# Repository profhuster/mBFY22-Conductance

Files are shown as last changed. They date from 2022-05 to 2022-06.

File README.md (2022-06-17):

# Conductivity *versus* Temperature using CircuitPython on a Microcontroller
# Introduction

The ESP32-S2 is an amazing little microcontoller. It has built in WiFi 
a true DAC (Digital to Analog Converter), multiple ADC's (Analog to
Digital Converters), and DIO (Digital In Out) pins.
The DAC is relatively rare in microcontollers but it
enables some unique experiments. In this project you will use the DAC to
control the voltage to a device, and two of the ADC's 
to measure the resistance (inverse of the conductance) of a device. 
The microcontroller will measure both the current through and voltage
across the device as the voltage across it changes and fit the result to
a line to get the resistance. I also have a list in an appendix of other 
applications of this project.

To make the project more interesting you will also wire a Type K
thermocouple to a microcontroller breakout board using a digital
protocol. A type K thermocouples can read from -200 °C to 1350 °C. You can
use the thermocouple to measure the temperature coefficient of the resistance and
other experiments.

# Guide to Project Files
- [Main Guide to Project](https://github.com/profhuster/mBFY22-Conductance/blob/19ab132cf7104593252cab7fcc826aaca93124e6/Conductivity-CircuitPython_22d.pdf) You should download 
this document and keep it open as you work.
- [Setting Up CircuitPython](https://github.com/profhuster/mBFY22-Conductance/blob/bd73491f5e60a5675a0e9d870f6eabee54c16e31/Setting_Up_CircuitPython_22a.pdf) This is the guide to installing 
CircuitPython on a Microcontroller. You need to do this before working on the project.

[Back to mBFY22 page](https://github.com/profhuster/mBFY22)

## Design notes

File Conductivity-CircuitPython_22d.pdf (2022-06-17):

Project Guide | Conductivity using CircuitPython Microcontollers | June 2022

INTRODUCTION
The ESP32-S2 microcontoller has a true DAC (Digital to Analog Converter.) This feature is relatively rare in microcontollers but it enables some unique experiments. In this project you will use the DAC to control the voltage to a device, and two of the ADC's (Analog to Digital Converters) to measure the resistance (inverse of the conductance) of a device.
The microcontroller will measure both the current through and voltage across the device as the voltage across it changes and fit the result to a line to get the resistance. I also have a list in an appendix of other applications of this project.
To make the project more interesting you will also wire a Type K thermocouple to a microcontroller breakout board using a digital protocol. A type K thermocouples can read from -200 °C to 1350 °C. You can use them to measure the temperature coefficient of the resistance and the transition temperature of high Tc superconductors. I set up a GitHub repository with all of the documents and code for this project at
https://github.com/profhuster/mBFY22-Conductance.

BILL OF MATERIALS
Items needed with approximate cost.
- Case, 3D printed – $2 of PLA filament.
- Half breadboard – $5.
- Lolin S2Mini microcontroller board – $5.
∘ Option: TinyS2 – ESP32-S2 Development Board from AdaFruit – $19.
∘ Adafruit ESP32-S2 Feather – $18.
- Thermocouple breakout board, MAX31855 – $15.
- Type K thermocouple – $10.
- Miscellaneous electronic supplies:
∘ 100 Ω resistor.
∘ Sample resistor <= 100 Ω.
∘ Hook up wire, 22AWG Solid Core.
- Total: $56

Tools, Equipment, and Software:
- Computer.
∘ Need to install Thonny editor/IDE. ∘ Optional: jupyter notebook.
- USB C cable.
- Soldering iron.
- Wire strippers.
- Optional:
∘ Wire cutter.
∘ Needle-nosed pliers.
Conductivity-CircuitPython_22d.odt | — 1 of 16 — | 2022-06-15, 20:26

Project Guide | Conductivity using CircuitPython Microcontollers | June 2022

GETTING STARTED
Follow the steps in the Setting Up CircuitPython to load CircuitPython onto the Lolin S2Mini microcontroller.The Lolin S2Mini.

HARDWARE
The pin assignments for the S2Mini are in Figure 1. To use on a
breadboard, I only use the outside pins. Almost any pin can be

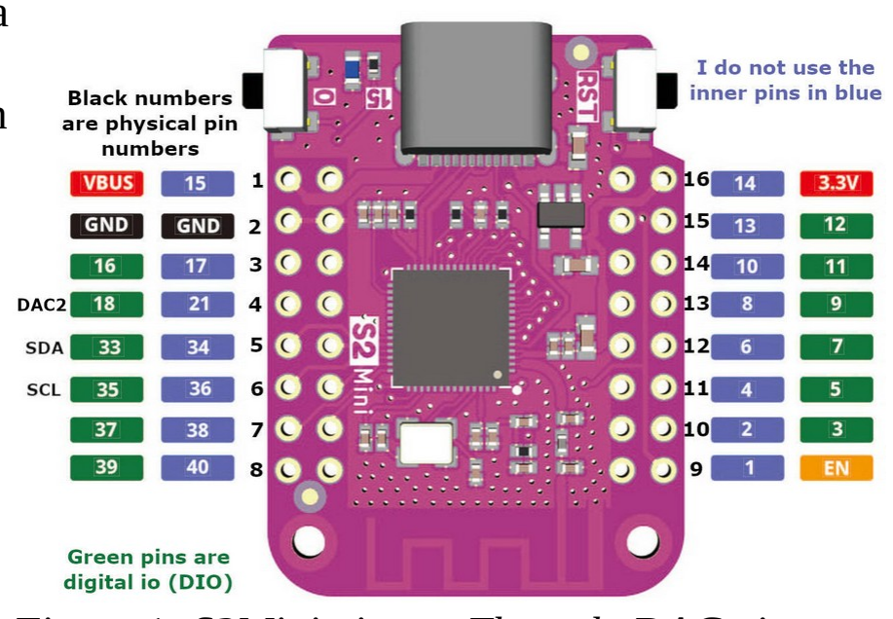
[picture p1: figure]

used for digital in/out and ADC, but only pins 18 (and 17 which is not wired up) have a DAC which can be used to output a voltage. The DAC has 8-bits of resolution (0 – 0xff.) Circuit-Python maps the DAC resolution to 16-bits (0 – 0xffff) so setting pin 18 from 0 to the max should gives= an output voltage of 0 to 3.3 V. In the first project you will test this out.

DAC Complication
The DAC’s on the ESP32S2 have internal pull-up resistors, so to get a decent output voltage range you need to supply a pulldown resistor. Figure 2 shows the output voltage versus DAC setting for different pulldown resistors. To get a good range on the DAC, we need to have 1 kΩ or less connected to the DAC

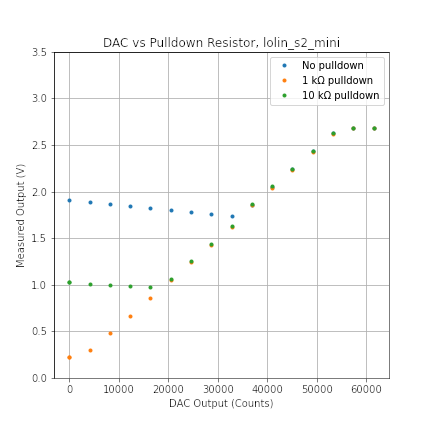
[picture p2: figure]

pin. Later when we design a circuit to measure conductance, we need to make sure it has an equivalent resistance of 1 kΩ or less.

Conductivity-CircuitPython_22d.odt | — 2 of 16 — | 2022-06-15, 20:26

Figure 1: S2Mini pinout. The only DAC pins are 17 on the inside row and 18. Not all pins have ADC’s. We will use pins 9, 11, and 12.

Figure 2: DAC output on pin 18 with different pulldown resistors.

Project Guide | Conductivity using CircuitPython Microcontollers | June 2022

PROJECT 1 – TAKE DAC VOLTAGE VERSUS DAC COUNTS DATA
See Figure 3 for a picture of the circuit.
- Plug the S2Mini into a breadboard.
- Wire GND to the blue “–“ power rail.
- Wire pin 16 to row 12 after the S2Mini.
- Wire pin 18 to the same row.
- Wire a 100 Ω resistor from the same row and to the ground rail. Note: the figure shows a 1 kΩ instead of 100 Ω. The Code
First you need to load the libraries we will be using to the S2Mini. From the zip file, locate the folder lib. Drag it to the CIRCUITPY disk. If it prompts you that the folder there exists, answer Replace, or copy anyway.
In your code the libraries (sometimes called modules) are im-

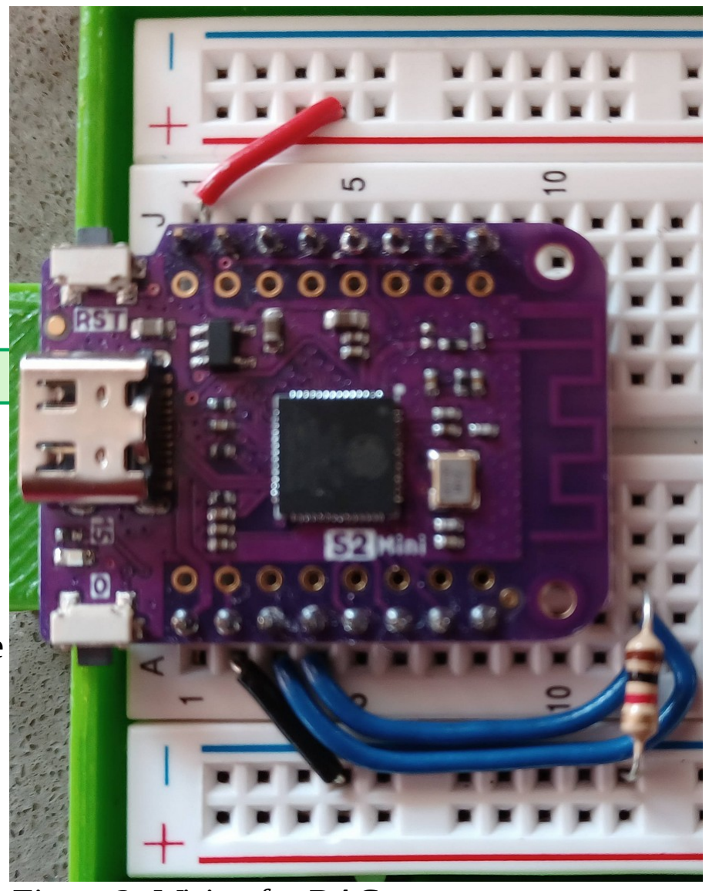
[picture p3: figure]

ported first. The library board imports the pins available for the specific board and a few other items. I encourage that you explore these libraries. You can do that at the python prompt by typing, for example,
>>> import board
>>> help(board)
>>> dir(board)
I do this a lot with libraries and objects so I can learn what can be done with CPy. The other source of information is searching the CircuitPython web site. (https://docs.circuitpython.org/en/latest/) The library analogio handles DAC and ADC functions for microcontrollers. I also import sleep and sqrt from standard python libraries.
This file for this code is testDAC.py. Note: The code on GitHub is slightly different. Please us the GitHub code. import board
import analogio
from time import sleep
from math import sqrt
Next I create variables that parameterize the program behavior. I strongly advocate the programming proverb Never bury a constant in your code; assign it to a variable or constant at the top of your code. Here I had to look up which pins are DAC compatible (pins 17 & 18) and which are ADC compatible (many pins.)
For each data point I I sleep for tADC seconds to give time for the DAC to settle then average over nAvg points. The variable counts sets the DAC voltage, the variables countsMax and countsInc set the loop for stepping the DAC. The CircuitPython library maps all DAC’s to 16 bits, so I use hex to code the maximum value as 0xffff. Setting an increment of 0x0400 gives 64 data point in the scan. I find hex easier than remembering 65535 and 1024.
dacPin = board.IO18
adcPin = board.IO16
nAvg = 10
tADC = 0.01
countsMax = 0xffff
countsInc = 0x0400
Conductivity-CircuitPython_22d.odt | — 3 of 16 — | 2022-06-15, 20:26

Figure 3: Wiring for DAC test.

Project Guide | Conductivity using CircuitPython Microcontollers | June 2022

To grab a pin for analog use, the analogio library does a lot of work for you. I set up the variable dToV to convert counts to voltage for ADC readings.
dac = analogio.AnalogOut(dacPin)
adc = analogio.AnalogIn(adcPin)
dToV = adc.reference_voltage / 0xffff
In this section you can input a comment that will get stored in the data file. I used this to describe the pull down resistors. I also print important information about the microcontoller and the code. The board_id variable describes the microcontoller, in this case the string is lolin_s2_mini. Note I print out the parameters for the run. Starting these lines with # makes it easier to import the data into an analysis program.
comment = input("Enter comment: ")

print(f"# board_id = {board.board_id}")
print(f"# dacPin: {dacPin}, adcPin: {adcPin}, dToV: {dToV}")
print(f"# nAvg: {nAvg}, tADC: {tADC}")
print(f"# {comment}")
Next I define a function that returns an ADC reading and its standard deviation. This is where the parameters nAvg and tADC are used. I strongly encourage my students to always be thinking about uncertainties in measurement. In this case the standard deviation tell you how spread out the measurements are.
def readADC():
sum = 0.0
sumSq = 0.0
for i in range(nAvg):
reading = adc.value * dToV sum += reading
sumSq += reading * reading sleep(tADC)

avg = sum / nAvg
std = sumSq / nAvg - avg * avg if std <= 0.0:
std = 0
else:
std = sqrt(sumSq / nAvg - avg * avg) return (avg, std)
Below is the main loop. It set the DAC value, sleeps, then reads the ADC and prints the result. I always use a # in the first line of comments, and make the data in comma separated columns, the CSV format. This makes reading and analyzing the data easy. Also note I manually add the last point otherwise I wouldn’t get a data point for the maximum value of the DAC.
for out in range(0, countsMax, countsInc):
print(f"{out}, ", end="")
dac.value = out
sleep(0.1)
(V, dV) = readADC()
print(f"{V}, {dV}")

out = 0xffff
print(f"{out}, ", end="")
dac.value = out
sleep(0.1)
(V, dV) = readADC()
print(f"{V}, {dV}")
Conductivity-CircuitPython_22d.odt | — 4 of 16 — | 2022-06-15, 20:26

Project Guide | Conductivity using CircuitPython Microcontollers | June 2022

These last two lines release the pins. If these lines are not included, when you rerun the code it can’t grab the pins.
dac.deinit()
adc.deinit()
Analyzing the DAC Data
The output is written in the Shell window at the bottom of Thonny. Below is an example run of the output: # board_id = lolin_s2_mini
# dacPin: board.IO18, adcPin: board.IO16, dToV: 5.03547e-05

# nAvg: 10, tADC: 0.01

# 1 k pulldown

0, 0.241481, 0.00211784
4096, 0.297284, 0.00316913 8192, 0.487575, 0.00245358 12288, 0.672477, 0.00304931 16384, 0.869571, 0.00223759 20480, 1.06437, 0.00316442 24576, 1.26018, 0.00292969 28672, 1.45058, 0.00276214 32768, 1.64508, 0.00169146 36864, 1.85078, 0.000976563 40960, 2.04587, 0.00195313 45056, 2.23348, 0.00195313 49152, 2.43148, 0.00239208 53248, 2.63266, 0.00338291 57344, 2.68199, 0.00276214
61440, 2.68199, 0.00276214
65535, 2.68199, 0.00276214
I cut and paste this into an editor, edit to delete any extra lines and save it with a file name that encodes the date and time the data was taken, 2022-04-28-1546.csv, for example.
I use jupyter notebooks running python to analyze the data. They are in the jupyter folder on GitHub. One nice thing about the CSV data format is that is can be read by many programs including spreadsheets like Microsoft Excel. Figure 4 is a plot from my jupyter notebook plotDAC.ipynb.
The curve looks linear between 5000 and
45000 counts and it does not go down to
zero volts nor up to 3.3 V. These are limitations we will have to work with when we make a conductivity measurement.
I took the data in Figure 2 using this program and different pull down resistors.

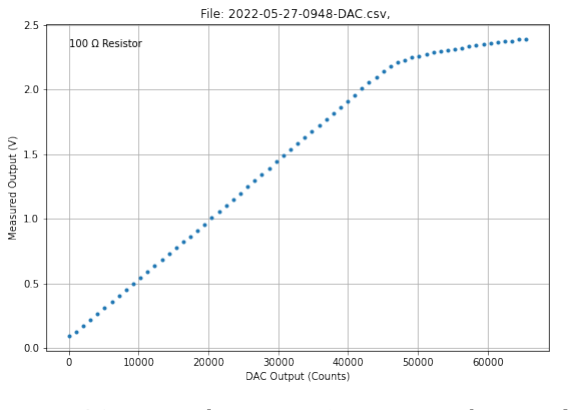
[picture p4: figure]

Conductivity-CircuitPython_22d.odt | — 5 of 16 — | 2022-06-15, 20:26

Figure 4: DAC output voltage versus input counts. The curve depends on the value of the pulldown resistor.

Project Guide | Conductivity using CircuitPython Microcontollers | June 2022

PROJECT 2: TWO-WIRE CONDUCTIVITY MEASUREMENT The next project will use the microcontoller to measure the resistance (inverse of the conductivity) of a device.
The basic idea, Figure 5, is that the voltage drop across the sensing resistance is the current through the sample. So

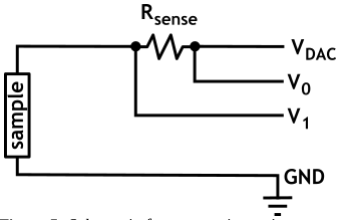
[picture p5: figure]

I sample=

V 0−V 1

Rsense
and

Vsample=V1
So

Rsample=

V sample

I sample

We will step VDAC from 0 to 3.3V, so a graph of Vsample versus Isample should be a straight line with a slope of Rsample. For each DAC setting, we will read V0 and V1 multiple times and get an uncertainty for each. We will carry the uncertainty through the linear fit to calculate an uncertainty for the resistance.
I wired this circuit up with a 100 Ω sense resistor and 69 Ω resistor for the sample.
Figure 6 shows a graph of V0 and V1 versus DAC setting. You can see at counts less than about 4000 the curves flattens out or

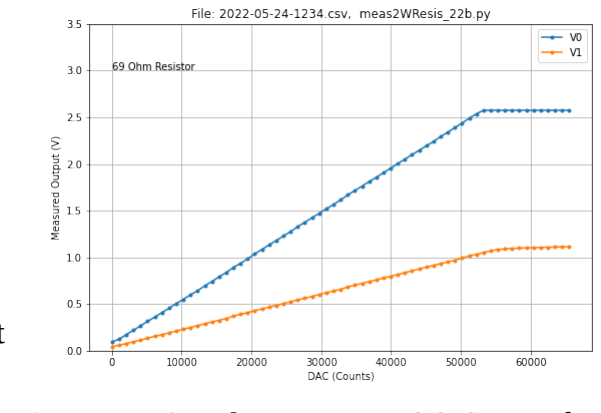
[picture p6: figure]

slightly rises. I believe this is an effect of the pull up resistor. At the higher end, the voltage does not go above 2.58 V. I believe this is a limit of the ADC. In between the two graphs look linear. In the software I will limit the data to DAC counts to
greater than 4000 and voltages less than 2.50.
In the software I actually average some number of ADC readings together at each DAC step. This gives more accuracy to each data point and I calculate the standard deviation for the point, so I also have an uncertainty estimate for each point.
Conductivity-CircuitPython_22d.odt | — 6 of 16 — | 2022-06-15, 20:26

Figure 5: Schematic for a two-wire resistance measurement.

Figure 6: V0 and V1 versus DAC Counts for a 60 Ohm resistor as a sample.

Project Guide | Conductivity using CircuitPython Microcontollers | June 2022

I do a linear fit with uncertainty to the data.
This gives both a measurement of the sample
resistance, but also an uncertainty estimate for
the resistance. Figure 7 is an example of one measurement.
Once the code for making the measurement

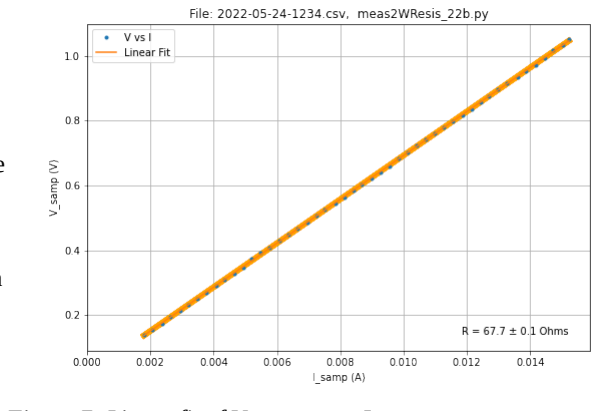
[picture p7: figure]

was checked and debugged, the basic resistance measurement is in a loop that measures the resistance versus time. Figures 8 & 9 show a run where the resistance is repeated. From running the program versus time, the standard deviation of the resistance measurements is about 0.1 Ω.

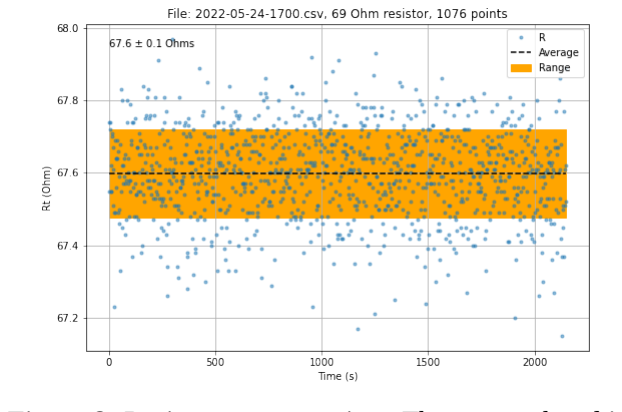
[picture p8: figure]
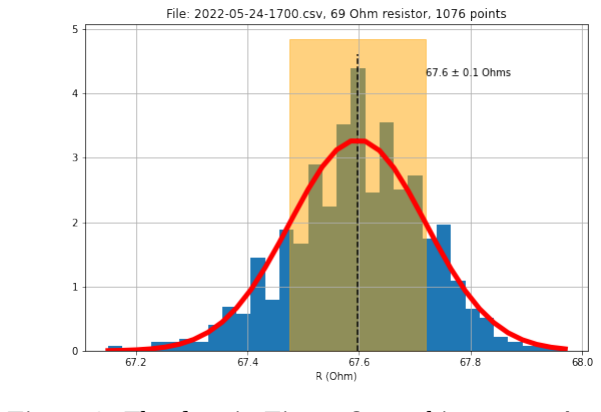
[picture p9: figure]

Conductivity-CircuitPython_22d.odt | — 7 of 16 — | 2022-06-15, 20:26

Figure 7: Linear fit of Vsample versus Isample.

Figure 8: Resistance versus time. The orange band is +/- one standard deviation.

Figure 9: The data in Figure 8 as a histogram. A normal distribution matching the average and standard deviation is shown.

Project Guide | Conductivity using CircuitPython Microcontollers | June 2022

The Hardware
A picture of the circuit is in Figure 10. The sample is a
68 Ω resistor. You can see the wires are tightly twisted and soldered to a two pin connector.
To wire the circuit:
- Wire the 3.3V to the “+” power rail (red.)
- Wire pin GND to the blue “-” ground rail (black.)
- Wire the DAC, pin 18 to the 100 Ω sensing resistor. Also wire that end of the resistor to pin DIO5 which is V0. They are the yellow wires in the figure.
- Finally the last wire of the sample connector is wired to ground, the “-” ground rail (black.)

The Code

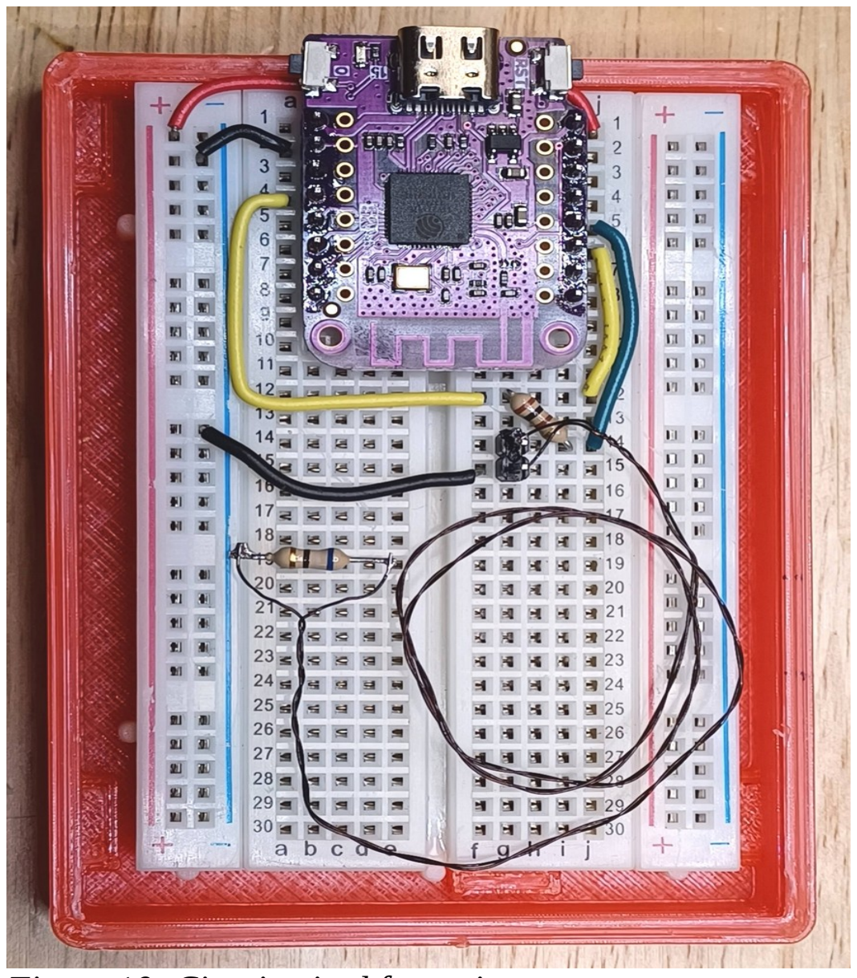
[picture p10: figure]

A lot of the code is the same as the previous project. The file is meas2WResis.py. I will just highlight the new code. The code below does a fit to a straight line and weights the fit by the uncertainty in the y-coordinate. Since I did not use numpy because only a subset of numpy is available as the ulab library. Instead I use the array library so I have to explicitly loop over the data. The function returns the best fit values for the intercept and slope and the covariance matrix.
# Do linear fit

def linReg(n, x, y, sigY):
"""linReg - linear fit with returned uncertainties.""" invSigY2 = 0
S = 0.0
Sx = 0.0
Sy = 0.0
Sxx = 0.0
Sxy = 0.0
for i in range(n):
invSigY2 = 1.0 / (sigY[i] * sigY[i]) S += invSigY2
Sx += x[i] * invSigY2
Sy += y[i] * invSigY2
Sxx += x[i] * x[i] * invSigY2
Conductivity-CircuitPython_22d.odt | — 8 of 16 — | 2022-06-15, 20:26

Figure 10: Circuit wired for resistance measurement. The sample is attached by a pair of twisted wires to the circuit.

Project Guide | Conductivity using CircuitPython Microcontollers | June 2022

Sxy += x[i] * y[i] * invSigY2

Delta = S * Sxx - Sx * Sx
a = (Sxx * Sy - Sx * Sxy) / Delta b = (S * Sxy - Sx * Sy) / Delta varA = Sxx / Delta
varB = S / Delta
covAB = -Sx / Delta
return (a, b, varA, varB, covAB) Next is the function that returns the resistance. First I create arrays for intermediate data and define first. # Make arrays for data
ISamp = array('f', nCounts * [0.0])
VSamp = array('f', nCounts * [0.0])
sigV = array('f', nCounts * [0.0])
first = True # Boolean to print nGood only once
The next part of the code loops over the DAC values. If you are not familiar with enumerate(), it is an iterator over an array, but it returns two values: a counting index, here the variable i, and the next array value, out. Next, the first time it is called, it prints the number of data points used in the linear fit. Finally it calculates the uncertainty in the resistance as the square root of the variance and returns both the fit value and its uncertainty.
def measureR():
global first, ISamp, VSamp, sigV

# Collect the data into arrays

nGood = 0
for (i, out) in enumerate(range(0, countsMax, countsInc)): dac.value = out
sleep(tADC)
(V0, dV0) = readADC(v0)
if out > 4000 and V0 < 2.65:
| (V1, dV1) = readADC(v1) ISamp[nGood] = (V0 - V1) / rSens VSamp[nGood] = V1 sigV[nGood] = sqrt(dV0 * dV0 + dV1 * dV1) if debug:

print(f"{out}, {ISamp[nGood]}, {VSamp[nGood]}, {sigV[nGood]}")
| nGood += 1

# On first call print the number of data points if first:

first = False
print(f"# {nGood} good points")

# Fit data to a line

(a, resis, varA, varB, covAB) = linReg(nGood, ISamp, VSamp, sigV) uncResis = sqrt(varB)
if debug:
print(f"# Resistance = {resis:.2f}, {uncResis:.2f}")

# Return resistance and uncertainty

return (resis, uncResis)
Conductivity-CircuitPython_22d.odt | — 9 of 16 — | 2022-06-15, 20:26

Project Guide | Conductivity using CircuitPython Microcontollers | June 2022

Finally the code below is the main loop that takes data. The function monotonic() returns the number of seconds since the microcontoller booted. The entire loop is in a try – finally structure. The reason for this is to release the pins when the program is stopped with a <Ctrl>C keystroke.
# Loop forever taking data

# Stop with ^C

t0 = monotonic()
try:
while True:
while monotonic() < t0 + loopTime: sleep(0.01)
t0 += loopTime
(R, sigR) = measureR()
print(f"{monotonic():.1f}, {R:.2f}, {sigR:.2f}") finally:
# Clean up

print("# Cleaning up")
dac.deinit()
v0.deinit()
v1.deinit()
Conductivity-CircuitPython_22d.odt | — 10 of 16 — | 2022-06-15, 20:26

Project Guide | Conductivity using CircuitPython Microcontollers | June 2022

PROJECT 3 – RESISTANCE VERSUS TEMPERATURE
The final step is to use a breakout board to measure the sample temperature with a thermocouple. A Type K thermocouple has a useful range of -200 oC (73 K) to 1350 oC. They are nice because they can be used for liquid nitrogen experiments. Thermocouples are hard to use without specialized circuits, but don’t fear! They are nicely handled with a $16 breakout board like this one. (https://www.adafruit.com/product/4101) We are going to add this to the previous project.
Hardware

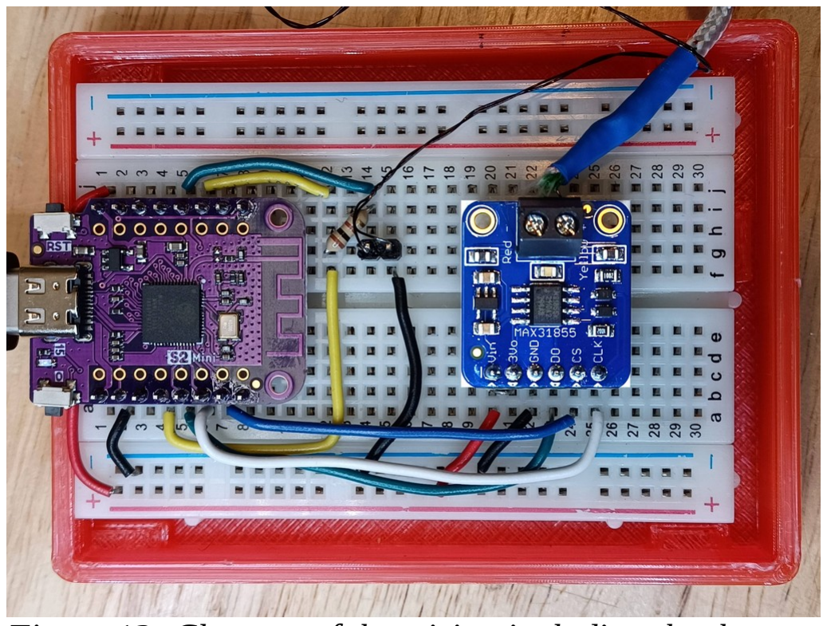
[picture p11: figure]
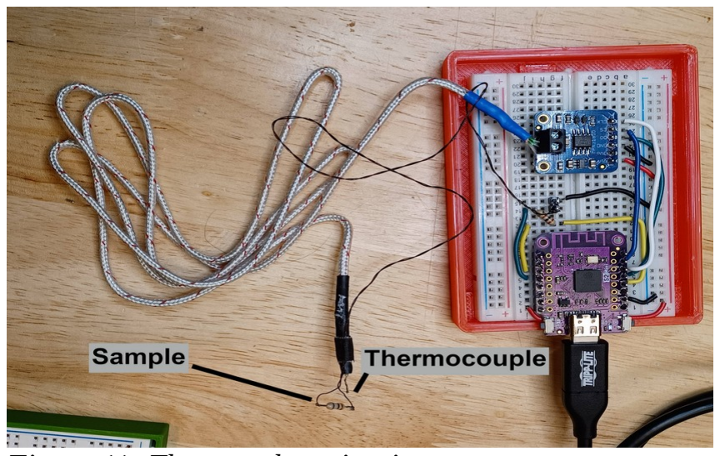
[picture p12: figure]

The overall device is shown in Figure 11, a close up of the wiring is in Figure 12.
The wiring is the same as the previous plus:
- Plug the breakout board into the breadboard.
- Wire S2Mini pin DIO33 to the DO (Data Out) pin on the breakout board (green wire.)
- Wire S2Mini pin DIO35 to the SCL pin on the breakout board (white.)
- Wire S2Mini pin DIO37 to the CS pin on the breakout board (blue.)
- Wire the 3.3V pin of the S2Mini across to the red “+” power rail on the breadboard (red.)
- Wire the breakout board VIN to the “+” power rail (red.)
- Put a bare wire between the VIN and 3V3 pins on the breakout board. (This can’t be seen in the figure because it is underneath the breakout board.
- Wire the GND pin on the breakout board to the “-” ground rail on the breadboard (black.)
- Screw the thermocouple into the breakout board. Once it is running, hold the thermocouple. If the temperature goes down, switch the wires.
The Code
The code is in file meas2WRvsT.py. In addition to the code for Project 2 it has the following code:
import digitalio
import busio
import adafruit_max31855
import microcontroller
import watchdog
Conductivity-CircuitPython_22d.odt | — 11 of 16 — | 2022-06-15, 20:26

Figure 11: The complete circuit.

Figure 12: Close up of the wiring including the thermocouple breakout board.

Project Guide | Conductivity using CircuitPython Microcontollers | June 2022

The first three lines import libraries needed for the MAX31855 breakout board. For a description of how this code was developed, see the appendix in the handout 2022-mBFY-Introduction.
spi = busio.SPI(board.IO35, board.IO36, board.IO33)
cs = digitalio.DigitalInOut(board.IO37)
max31855 = adafruit_max31855.MAX31855(spi, cs)
The first line defines the SPI interface using the pins designated. The second line defines the chip select pin. The last line uses the AdaFruit library for this breakout board. I chose this board because it is only for Type K thermocouples. If you have a different type of thermocouple or a platinum resistance thermometer, there are other boards you can use.
The first three lines import libraries needed for the MAX31855 breakout board. For a description of how this code was developed, see the appendix in the handout 2022-mBFY-Introduction. Once the breakout board is ready reading the temperature is as simple as reading the value of max31855.temperature. Easy peasy!
The code allows the user to enter a comment that is stored in the data file, but I didn’t want the code to hang up if the data be taken remotely. The solution is a watchdog timer. You set the watchdog and if it isn’t fed or canceled, it goes off and does some contingent action. Here is the code around getting a comment:
wdt = microcontroller.watchdog
wdt.timeout = 10
wdt.mode = watchdog.WatchDogMode.RAISE
try:
comment = input("Enter comment: ")

except watchdog.WatchDogTimeout as e:
comment = "No comment"
wdt.deinit()
It sets the watchdog with a 10 second timeout. It set the mode of the watchdog to raise an exception. If you don’t set the mode, the microcontoller is completely reset!
Now the line getting a comment is in a try – except structure. If no comment is entered in 10 seconds, it sets the comment to “no comment”.
Finally the watchdog is deinitialized, or turned off.
print(f"{monotonic():.1f}, {R:.2f}, {sigR:.2f}, {max31855.temperature:.2f}")
Finally, getting the temperature is easy. The dynamic variable max31855.temperature retrieves the thermocouple temperature.

AN EXPERIMENT
With the setup as built I measured the resistance versus
temperature. I do not know what type of resistor it is in the device. I taped the sample and thermocouple wires

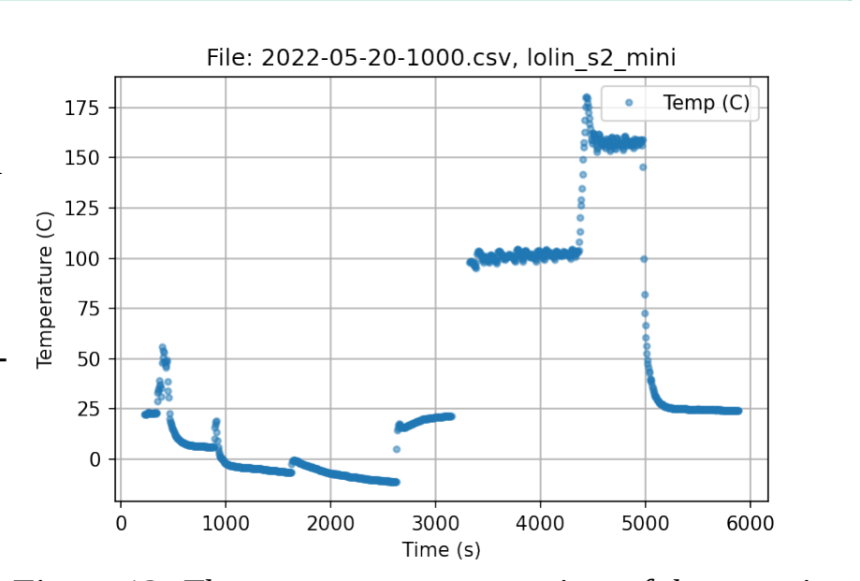
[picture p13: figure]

together to the thermocouple was about 2 mm away from the sample.
Figure 13 shows the temperature versus time as I cooled and heated the sample and thermocouple.
The result is shown in Figure 14. The temperature coefficient of resistance is -168 ppm/°C. (ppm is parts per million.)
Conductivity-CircuitPython_22d.odt | — 12 of 16 — | 2022-06-15, 20:26

Figure 13: The temperature versus time of the experiment.

Project Guide | Conductivity using CircuitPython Microcontollers | June 2022

Finally, Figure 14 shows the resistance is temperature
dependent. The temperature dependence is usually give
as ppm (Parts Per Million) per degree Celsius. The value
of about -200 ppm/°C. I do not know what type of resistor this is, but, for example, carbon film resistors are quoted as having a temperature coefficient of -200

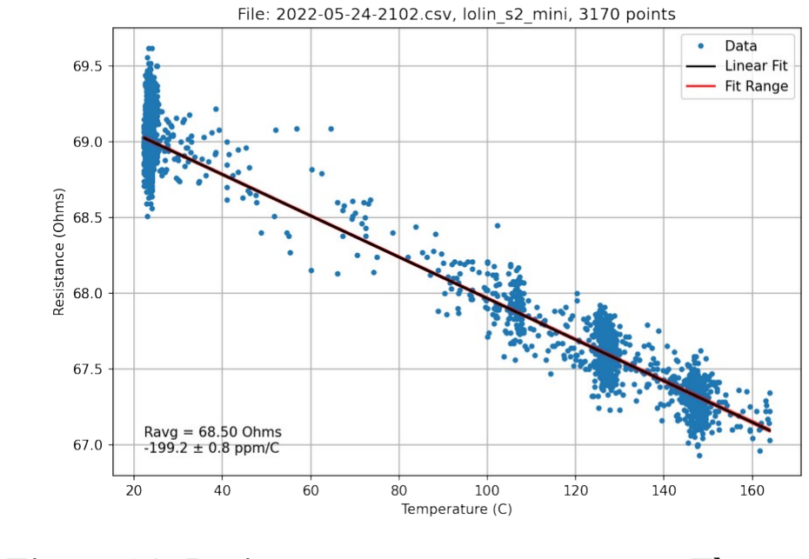
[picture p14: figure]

ppm/°C, so this value is right on that value, probably just a change occurance.

EXTENSION PROJECT: FOUR-WIRE CONDUCTIVITY MEASUREMENT The next project will use the microcontoller to measure the re-

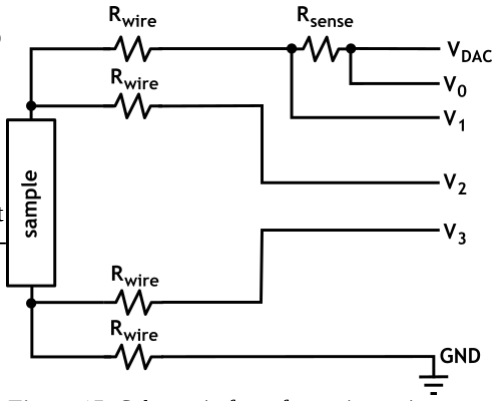
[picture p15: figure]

sistance (inverse of the conductivity) of a device. If you want to
put the device some distance away, like in a cryostat, the resistance of the wires would be added to the resistance of the device. This can be significant for some experiments. A standard, and very clever, method to avoid the added resistance of the wire is to use a four-point measurement technique.
The basic idea, Figure 5, is that you two wires to supply current through the sample, and two different wires to measure the voltage across the sample as close to the sample as possible. Voltage measurements are be made with only tiny amounts of current, so the ohmic loss in the voltage-measuring wires is insignificant. Also since tiny currents flow through the voltage measuring circuit, nearly all of the current measured flowing through the sensing resistor also flows through the sample. So

I sample=

V0−V1

Rsense
and

Vsample=V2−V3

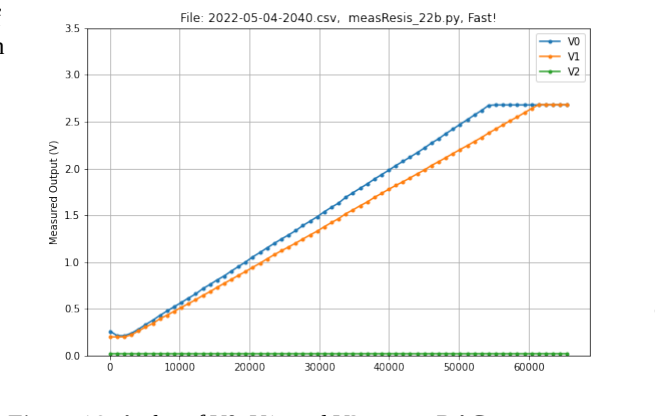
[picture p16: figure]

We will step VDAC from 0 to 3.3V, so a graph of Vsample versus Isample should be a straight line with a slope of Rsample.
I wired this circuit up with a 100 Ω sense resistor and about 69 Ω for the sample.
Figure 6 shows a graph of V0 and V1 versus DAC setting. You can see at counts less than
about 4000 the curves flattens out or slightly
Conductivity-CircuitPython_22d.odt | — 13 of 16 — | 2022-06-15, 20:26

Figure 15: Schematic for a four-wire resistance measurement. The Rwire's represent potentially long wires of unknown resistance.

Figure 16: A plot of V0, V1, and V3 versus DAC counts.

Figure 14: Resistance versus temperature. The temperature coefficient of resistance is about -200 ppm/°C.

Project Guide | Conductivity using CircuitPython Microcontollers | June 2022

rise. I believe this is an effect of the pull up resistor. At the higher end, the voltage does not go above 2.65 V. I believe this is a limit of the ADC. In between the two graphs look linear. In the software I will limit the data to DAC counts greater than 4000 and voltages less than 2.65.
In the software I actually average some number of ADC readings together at each DAC step. This gives more accuracy to each data point and I calculate the standard deviation for the point, so I also have an uncertainty estimate for each point.
I do a linear fit with uncertainty to the data.
This gives both a measurement of the sample
resistance, but also an uncertainty estimate for the resistance. Figure 7 is an example of one measurement.
Once the code for making the measurement

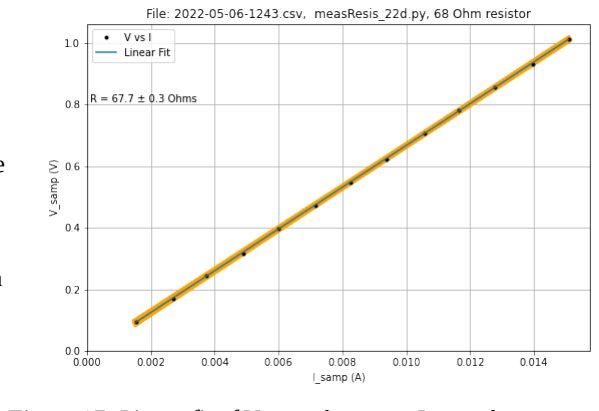
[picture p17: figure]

was checked and debugged, the basic resistance measurement is in a loop that measures the resistance versus time. Figures 8 & 9 show a run where the resistance is repeated. From running the program versus time, the standard deviation of the resistance measurements is about 0.1 Ω.

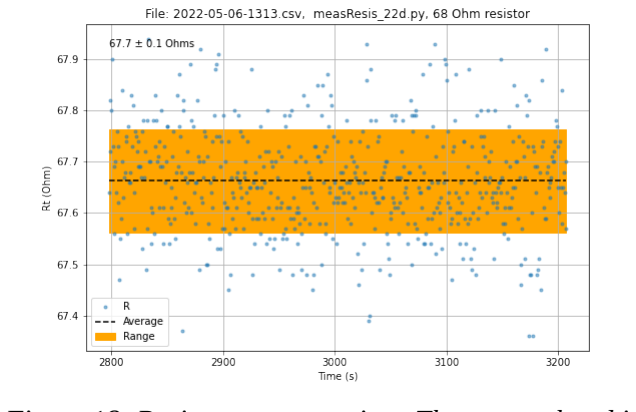
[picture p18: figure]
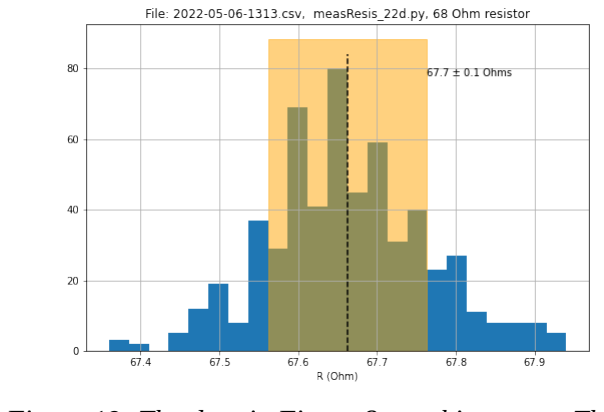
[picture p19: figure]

Conductivity-CircuitPython_22d.odt | — 14 of 16 — | 2022-06-15, 20:26

Figure 17: Linear fit of V_sample versus I_sample.

Figure 18: Resistance versus time. The orange band is +/- one standard deviation.

Figure 19: The data in Figure 8 as a histogram. The data appears to be normally distributed.

Project Guide | Conductivity using CircuitPython Microcontollers | June 2022

The Hardware
A picture of the circuit is in Figure 10. The sample is a
68 Ω resistor. You can see there are two wires soldered to each end of the resistor. The four wired are tightly twisted and soldered to a four pin connector.
To wire the circuit:
- Wire pin GND to the blue “-” ground rail.
- Wire the DAC, pin 18 to the 100 Ω sensing resistor. Also wire that end of the resistor to pin DIO5 which is V0. They are the yellow wires in the figure.
- The other end of the sensing resistor is wired to both the sample connector and pin DIO7, V1 (green.)
- The second wire of the sample connector is wired to pin DIO9, V2 (blue.)

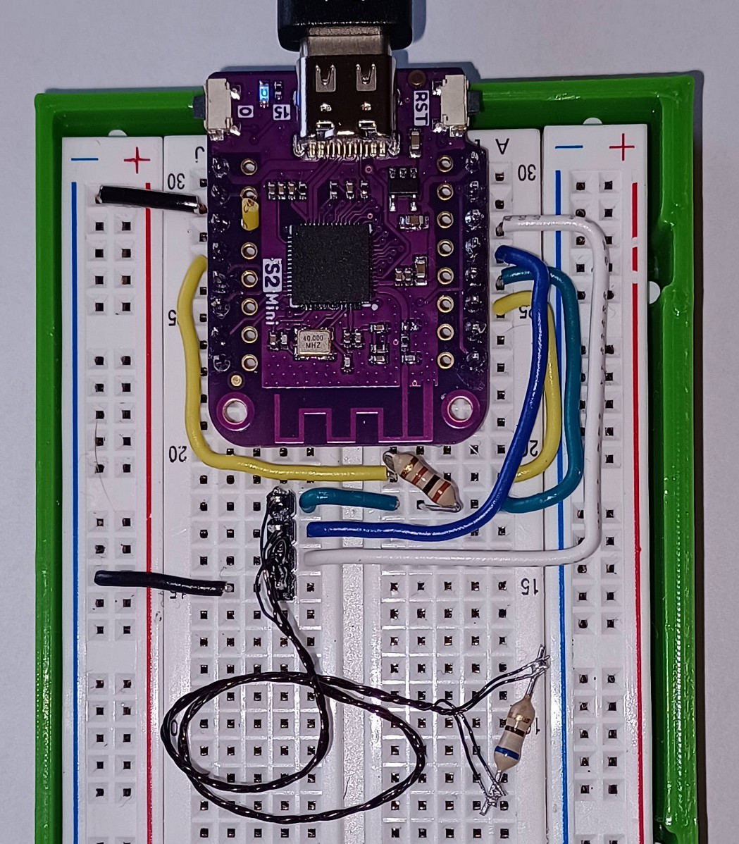
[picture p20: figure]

- The third wire of the sample connector is wired to pin DIO11, V3 (white.)
- Finally the last wire of the sample connector is wired to ground, the “-” ground rail (black.)

The Code
The code has some straightforward changes, using four ADC values to calculate Isample and Vsample. The code file is
meas4WRvsT_22a.py.

EXTENSIONS
1) The ESP32S2 has a built-in WiFi, so you can program it to connect with a WiFi and post its data to a cloud server. A popular protocol is MQTT, and a freee server I use is https://io.adafruit.com/.
2) The DAC on the S2Mini has issues like not going down to 0V and not being linear versus the counts. These are probably related issues. There are two ways to improve this:
a) Figure 13 shows how to wire the DAC to ground with a lower resistance, like 100 Ω, then use an op amp to provide a low impedance voltage source. I love the MCP6022 op amp. It works on 3.3 V supply, has rail to rail input and output, comes in plastic DIP that plugs into breadboards, and has a gain-bandwidth of 10 MHz. It is a good practice to wire a 1 uF capacitor from 3.3 V to GND at the op amp.

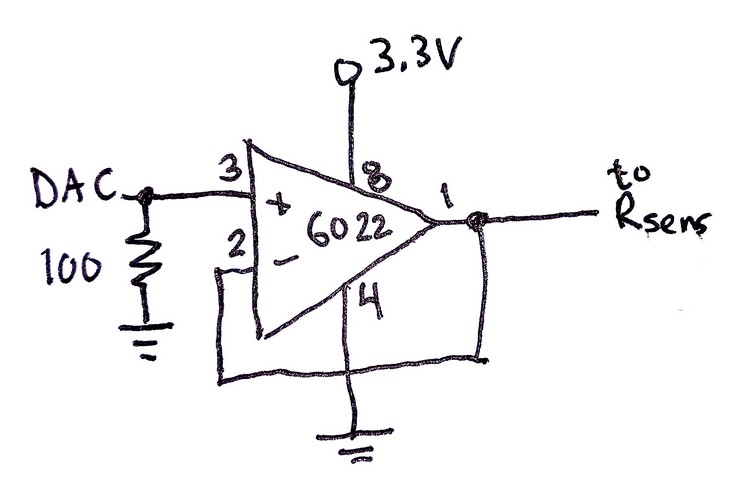
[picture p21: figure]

Conductivity-CircuitPython_22d.odt | — 15 of 16 — | Figure 21: An op amp circuit to buffer 2022-06-15, 20:26
the S2Mini DAC.

Figure 20: Circuit wired for four-point resistance measurement. The sample is attached by a bundle of four twisted wires to the circuit.

Project Guide | Conductivity using CircuitPython Microcontollers | June 2022
b) You can use an external DAC output board to provide the voltage to the circuit. These board cost less
than $10. See https://www.adafruit.com/product/935
The ADC part of the circuit can also be improved:
3) Instrumentation amplifiers can be used for
more accurate differential measurements
of the voltage across Rsens and the sample, Figure 8. For low resistance samples the gain of the amplifier measuring the sample can be increase up to G = 1000. Figure 8 is a schematic from a high Tc superconductor experiment using a different

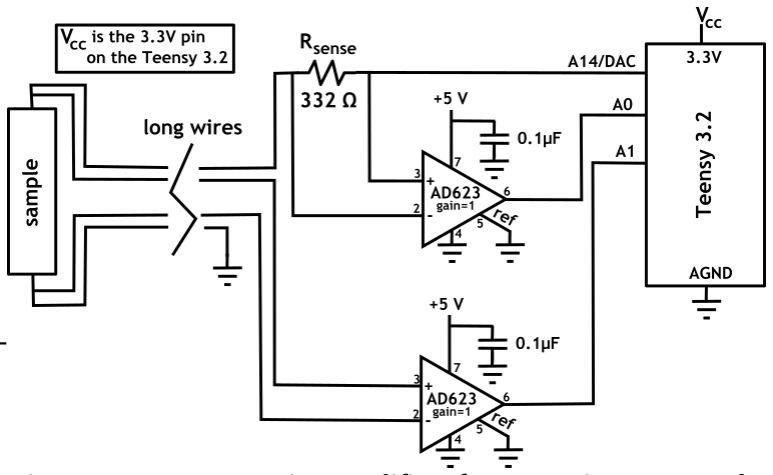
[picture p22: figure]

microcontroller. (The Teensy 3.2 is my favorite microcontroller for critical applications. It does not have a version of Circuit-Python, but you can run MicroPython on it.)
4) For working down to cryogenic temperatures a platinum resistance thermometer
can be used. The 4-POINT TC
EXPERIMENT KIT from
https://quantumlevitation.com/ has a PT-100 (100 Ω) resistor built in. You can program the microcontroller to measure its resistance or use a PRT breakout board like
https://www.adafruit.com/product/3328 which is connected to the microcontroller with a SPI protocol.
5) For a simple cryostat, use a sand cryostat. A sand cryostat is just an insulated foam cooler full of sand. You bury your experiment in the sand, pour liquid nitrogen in until it stops violently boiling and wait. It takes 5+ hours to warm back up to room temperature, so that makes a very nice run for high Tc superconductor measurements.
6) You can modify the code to measure the I-V curve for a diode. This opens the door for measuring Vforward in LED’s to get Plank’s constant or measuring the bandgap of a diode versus temperature.
7) You can make a transistor characterizing device. You would
also wire the second DAC, pin 17 on the inside row, to provide a base voltage, then trace out the emitter-collector response versus base voltage, like in Figure 23.

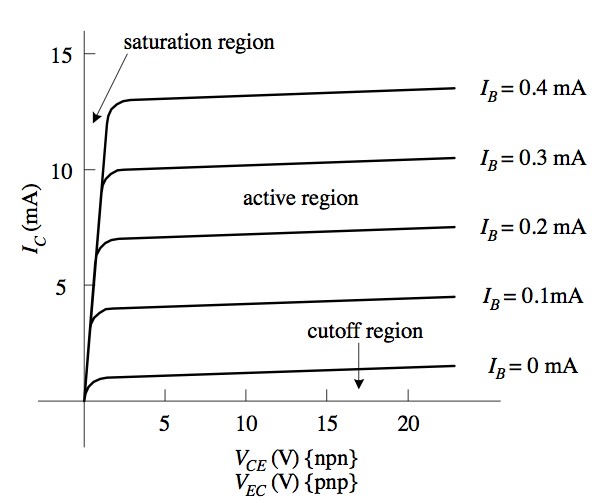
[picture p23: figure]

Conductivity-CircuitPython_22d.odt | — 16 of 16 — | 2022-06-15, 20:26

Figure 22: Instrumentation amplifiers for measuring Vsens and Vsample.

Figure 23: Bipolar transistor curve trace.

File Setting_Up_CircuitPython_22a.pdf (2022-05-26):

First Steps | Setting Up a CircuitPython Microcontroller | June 2022

INTRODUCTION
CircuitPython runs on many recent microcontollers, over 300 different boards. To get started go to https://circuitpython.org/downloads and search for your microcontoller board. You will not see the older, classic boards like the Arduino Uno – it just is does not have the right capabilities. I would not recommend proceding if your microcontoller board is not listed on CircuitPython.org.
I was searching the CircuitPython reddit and found CPy running on a $4 microcontroller. (https://www.reddit.com/r/circuitpython/comments/p9c09l/circuitpython_on_4_lolin_s2_mini_esp32s2_wusb_c/) I ordered several Wemos/Lolin S2Mini through AliExpress.com and found they work fine. I have ordered them twice and found it takes about three weeks for them to arrive. These are the devices I am using for the workshop.

INSTALLING CIRCUITPYTHON
1) Go to the download site for the S2 Mini here. (https://circuitpython.org/board/lolin_s2_mini/) On the right side of the page click the button [DOWNLOAD .BIN NOW]. This will download the latest stable CPy release. When I wrote this it was named adafruit-circuit-
python-lolin_s2_mini-en_US-7.3.0.bin.
2) Navigate to the ESP Web Flasher web site here. (https://nabucasa.github.io/esp-web-flasher/)
3) Plug the microcontoller into your laptop.
4) You need to get the microcontoller into the bootloader mode. There are helpful directions at the bottom of the download page.
5) On the S2Mini, hold down the boot button labeled 0, press and release the reset button labeled RST on the S2 Mini, wait a second, then release the boot button.
6) Click [Connect] button on the web page. A common response is
Connecting...
Connected successfully.
Try hard reset.
[Object.debug:187] Finished read loop
Error: Couldn't sync to ESP. Try resetting.
This means you did not get the bootloader to respond.
7) At this point it often takes several attempts to connect to the device. If the above button presses don’t work try:
a) Press the reset button on the microcontoller labeled RST on the S2 Mini. Connect again.
b) It often takes several attempts.
8) When it works you will see something like
Chip type ESP32-S2
Connected to ESP32-S2
MAC Address: 84:F7:03:D8:25:82 Uploading stub...
Running stub...
Stub is now running...
Detecting Flash Size
FlashId: 0x164020
Flash Manufacturer: 20
Flash Device: 4016
Auto-detected Flash size: 4MB
9) Click the [Erase] button on the web page, then [OK]. It takes about 20 seconds to erase the flash memory.
10) Click the top line button [Choose a file …]. Navigate to the fie you downloaded, select and click [Open].
11) Click [Program]. It takes about 40 seconds to flash. The output will look something like
Image header, Magic=0xFF, FlashMode=0xFF, FlashSizeFreq=0xFF
Setting_Up_CircuitPython_22a.odt | — 1 of 2 — | 2022-05-26, 13:55

First Steps | Setting Up a CircuitPython Microcontroller | June 2022

Writing data with filesize: 1420576
Erase size 1420576, blocks 87, block size 0x4000, offset 0x0000, encrypted no
Took 32228ms to write 1420576 bytes
Erase size 0, blocks 0, block size 0x4000, offset 0x0000, encrypted no
To run the new firmware, please reset your device.
12) Press the reset button on the S2 Mini. After a few seconds a disk named CIRCUITPY will show up on your system. You are done uploading CPy!
13) If you open the disk you will see a folder named lib, and two files, boot_out.txt and code.py.
14) Open Thonny, click Tools ➔ Options… | Interpreter. From the interpreter drop down menu select ➔ | Circuit-
Python (generic). In the port menu you should see your S2 Mini. Select it and click [OK]. On Macs is is listed as something like S2 Mini (/dev/cu.usbmodem487F1A2B9F8E). On Windows it is a COM port.
15) In the lower window label Shell, you may see the python prompt after a few seconds. If not click the stop
icon, , and it should respond with the python prompt. If not you can try pressing the reset button again re 🛑 | -
connecting to the port, pressing the stop sign. It will eventually show up.
Setting_Up_CircuitPython_22a.odt | — 2 of 2 — | 2022-05-26, 13:55

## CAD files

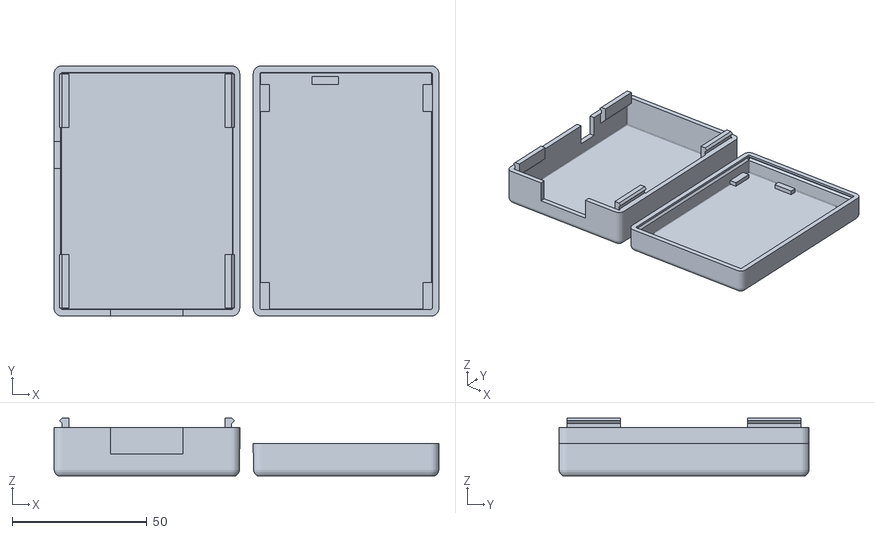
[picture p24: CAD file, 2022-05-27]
Cases-3D_Print/Conductivity_22a-all.stl
143.0 x 93.0 x 21.5

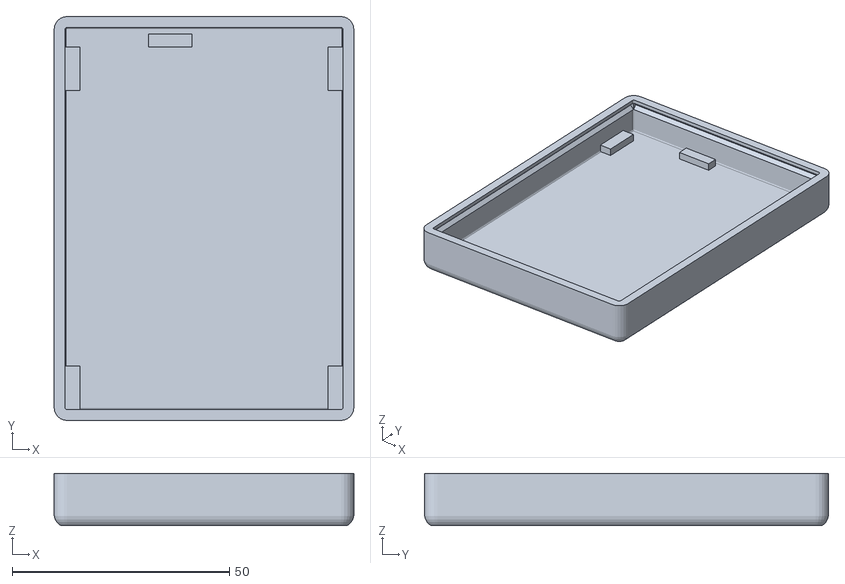
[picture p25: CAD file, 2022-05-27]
Cases-3D_Print/Conductivity_22a-bottom.stl
69.0 x 93.0 x 12.0

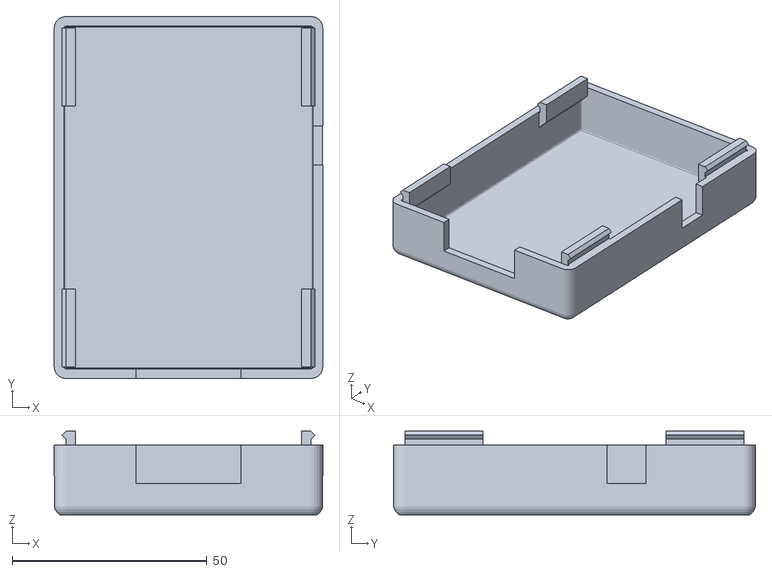
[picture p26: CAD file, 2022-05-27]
Cases-3D_Print/Conductivity_22a-top.stl
69.0 x 93.0 x 21.5

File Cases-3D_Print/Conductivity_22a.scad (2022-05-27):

/*
 * Half_Breadboard_Rnd_22a
 * ProfHuster@gmail.com
 * 2021-02014
 *
 * This is case that holds a half breadboard
 * 
 * v21a - Initial build
 * v21b - Add lid
 * v21c - Parameterized snaps in lid
 *        Breadboard is "upsidedown"
 * v22a - Making 1/2 breadboard project box
 *        Added blocks to position BB
 */
include <screws.scad>
include <RoundedBottomBox_21f.scad>

eps = 0.1;
eps2 = 2 * eps;
$fn=24;

echo("\n==== S2Mini_Stepper_Case ====\n");

printBase = false;
flipLid = true;
printLid = true;
printHBB = false;
// RPiRndLid();
// BREADBOARD PARAMETERS
// Half Breadboard
boardL = 83;
boardW = 56;
boardH = 9.5;

// Model tabs as square of 2x2x6 mm
tabL = 2;
tabH = 6;
// Positions of tabs on BB
tabX = [56, 56, 4, 50]; 
tabY = [14, 68, 83, 83];

// CASE PARAMETERS
caseTh = 2.5;
caseR = 3;
caseAngle = 30;
caseClrX = 3; // clearance around board for snaps
electClr = 10; // Height of electronics above bb

caseX = boardW + tabL + 2*caseClrX + 2*caseTh;
caseY = boardL + tabL + 1*caseClrX + 2*caseTh; // snap only in back
caseZ = boardH + caseTh;
lidZ = 18;

// Blocks to position breadboad
lBl = 10;
hBl = 2;
wBl = [4,4,4,4,3.0];
xBl = [caseTh, caseTh, caseX-caseTh-wBl[2], caseX-caseTh-wBl[3], 
        (caseX-caseTh-wBl[4])/2];
yBl = [caseTh, 86-lBl, caseTh, 86-lBl, 86];
zBl = caseTh;
thBl = [0, 0, 0, 0, 90];

// Lid Stuff
// Snap parameters
// Stick up tabs with snap ridges
// X,Y,L,lidZ,R,TH,Angle
srX0 = [0, 0, caseX, caseX];
srY0 = [20+caseTh+0.5, caseY-caseTh-0.5, 
           caseTh+0.5, caseY-caseTh-20-0.5];
srL0 = [20, 20, 20, 20];
srAngX0 = [0, 0, 0, 0];
srAngY0 = [180, 180, 180, 180];
srAngZ0 = [180, 180, 0, 0];
srParams0 = [srX0, srY0, srL0, srAngX0, srAngY0, srAngZ0];

// Lid Vents
hV1=10;
hV2=10;
RPventLX = [21, caseX+eps]; // Clearance for S2Mini, hole for wires
RPventLY = [0, 55];
RPventLZ = [lidZ-hV1+eps,lidZ-hV2+eps];
RPventLW = [27, 10];
RPventLH = [hV1,hV2];
RPventLL = [2*caseTh,2*caseTh];
RPventLAng = [0,90];


// Bottom
module BBRndCase(){
  union(){
    difference(){
      color("lightblue")
      RoundedBottom(caseX,caseY,caseZ,caseR,
        caseTh,caseAngle);
    }
    // Add positioning block for BB
    for(i=[0:len(xBl)-1]){
        color("lavender")
            translate([xBl[i],yBl[i],zBl])
            rotate([0,0,thBl[i]])
            cube([wBl[i],lBl,hBl]);
        
    }
  }
}

module RPiRndLid(){
  union(){
    difference(){
      color("wheat") 
      RoundedLid(caseX,caseY,lidZ,caseR,
          caseTh,caseAngle, srParams0);
      // Access holes (I call "vents")
      for(i = [0:len(RPventLX)-1]){
        translate([RPventLX[i],
          RPventLY[i]-eps, 
          RPventLZ[i]])
          rotate([0,0,RPventLAng[i]])
          color("yellow")
          cube([RPventLW[i],RPventLL[i],RPventLH[i]]);
      }
    }
  }
}



if(printBase){
  BBRndCase();
}

if(printHBB){
    translate([caseTh+caseClrX,caseTh+0.5,caseTh])
        halfBB();
}

if(printLid){
  if(flipLid){
    translate([-caseX-5,0,0])
      RPiRndLid();
  } else {
    translate([caseX,0,caseZ+lidZ+4])
      rotate([0,180,0])
      RPiRndLid();
  }
}

module halfBB(){
    color("pink"){
        cube([boardW, boardL,, boardH]);
        for(i = [0:len(tabX)-1]){
            echo(i);
            translate([tabX[i], tabY[i], 0])
                cube([tabL, tabL, tabH]);
        }
    }
}

// EOF

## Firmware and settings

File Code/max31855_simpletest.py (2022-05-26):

# SPDX-FileCopyrightText: 2021 ladyada for Adafruit Industries
# SPDX-License-Identifier: MIT

"""
max31855_simpletest

Modified by ProfHuster@gmail.com to work on Lolin S2Mini

2022-05-18

S2Mini board import has no SPI()
board.
    - SCK = board.IO7
    - MISO = board.IO9
    - MOSI = board.IO11 (don't need for MAX31855
I will use board.IO5 for CS.

From documentation on busio.SPI
class busio.SPI(
    clock: microcontroller.Pin, 
    MOSI: Optional[microcontroller.Pin] = None,
    MISO: Optional[microcontroller.Pin] = None,
    half_duplex: bool = False)
"""

import time
import board
import digitalio
import adafruit_max31855

if 'lolin_s2_mini' in board.board_id:
    import busio
    print("S2Mini")
    spi = busio.SPI(board.IO35, board.IO36, board.IO33)
else:
    print("Not S2Mini")
    spi = board.SPI()

cs = digitalio.DigitalInOut(board.IO37)

max31855 = adafruit_max31855.MAX31855(spi, cs)
while True:
    tempC = max31855.temperature
    tempF = tempC * 9 / 5 + 32
    print(f"Temperature: {tempC:.2f} C {tempF:.2f} F ")
    time.sleep(1.0)

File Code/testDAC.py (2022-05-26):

"""
testDAC.py
Sets the DAC and reads the ADC.

2022-04-28
ProfHuster@gmail.com
"""
import analogio
import board
from time import sleep
from math import sqrt

dacPin = board.IO17
dac = analogio.AnalogOut(dacPin)
adcPin = board.IO18
adc = analogio.AnalogIn(adcPin)
dToV = adc.reference_voltage / 0xffff
nAvg = 10
tADC = 0.01

print(f"# dacPin: {dacPin}, adcPin: {adcPin}, dToV: {dToV}")
print(f"# nAvg: {nAvg}, tADC: {tADC}")

def readADC():
    sum = 0.0
    sumSq = 0.0
    for i in range(nAvg):
        reading = adc.value * dToV
        sum += reading
        sumSq += reading * reading
        sleep(tADC)
        
    avg = sum / nAvg
    std = sqrt(sumSq / nAvg - avg * avg)
    return (avg, std)

for out in range(0, 0xffff, 0x1000):
    print(f"{out}, ", end="")
    dac.value = out
    sleep(0.1)
    (V, dV) = readADC()
    print(f"{V}, {dV}")

out = 0
print(f"{out}, ", end="")
dac.value = out
sleep(0.1)
(V, dV) = readADC()
print(f"{V}, {dV}")

dac.deinit()
adc.deinit()
# EOF

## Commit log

2022-05-26 The CircuitPython code for the project.
    The folder includes the lib modules needed as well as different testing python scripts.
2022-05-27 Add 3d print files for case
    [Conductivity_22a-all.stl, Conductivity_22a-bottom.stl, Conductivity_22a-top.stl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]
